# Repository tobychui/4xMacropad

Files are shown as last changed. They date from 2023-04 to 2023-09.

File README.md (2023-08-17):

## CH552G DIY Mechanical Keyboard Archives
This archive stores all the required design files for DIY macropads / keyboard of all sizes and layouts. If you are not experience enough to build one or you just want to get a sample before making a few for yourself, you can also find pre-assembled samples on my [Tindie Store](https://www.tindie.com/stores/tobychui/). 

Gerber files of PCB files will be released with each of the new layout release without the schematics. The schematics will be released following the next layout / design to make sure I got enough funding to iterate more layout and open source them for free. Thank you for your understanding!

## 4xMacropad

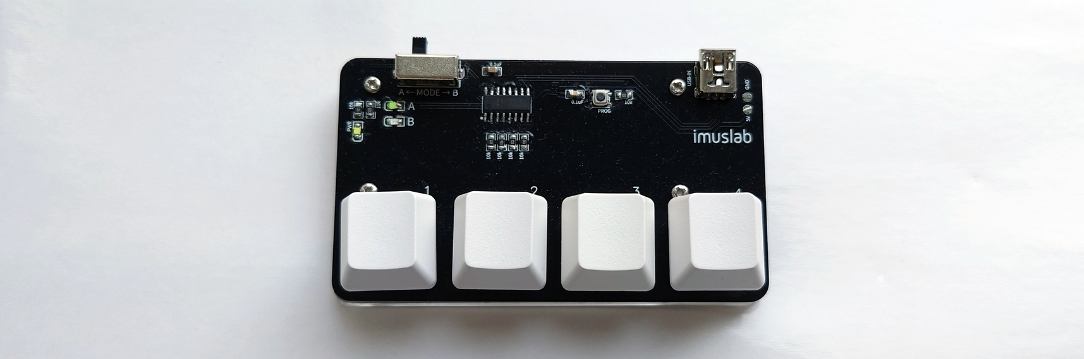
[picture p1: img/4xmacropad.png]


An ultra low cost, 4 keys mechanical macropad using CH552G. See the ```/4xMacropad/ ```folder.

## 4x5 Macro-numpad

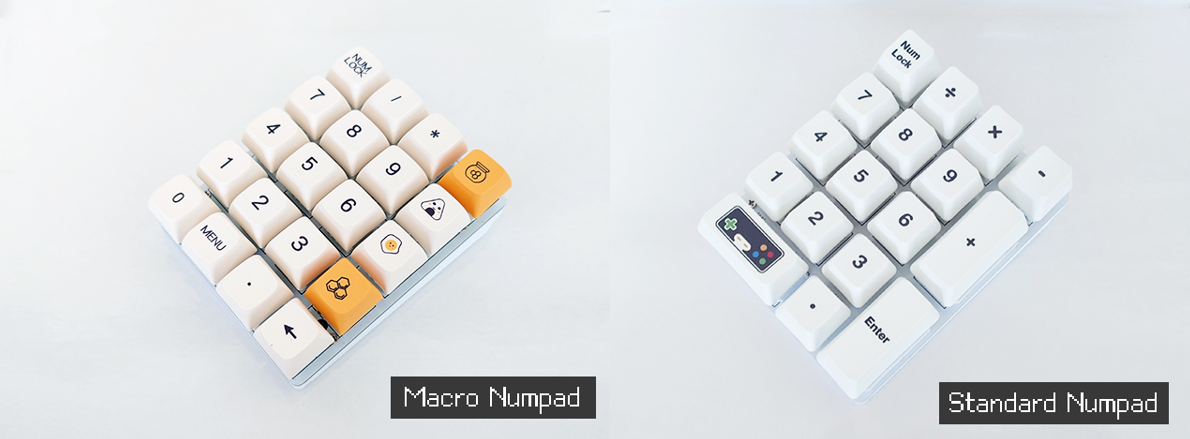
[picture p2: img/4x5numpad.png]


Another ultra low cost macropad + numpad powered by CH552G with two layouts on the same PCB. See the ```/4x5Macro-Numpad/``` folder.

### Build Instruction

1. Send the PCB to print (See /PCB)

2. Purchase all the required materials (See BOM list)

3. 3D print the base plate (See /3D Model)

4. Install the required Arduino library for CH552G and drivers

5. Visit [4-key Macropad | imuslab](https://tobychui.github.io/4xMacropad/) (4xMacropad only) or modify the sketch in /firmware folder

6. Flash the CH552G with the sketch

### Program Flashing Instructions

As all the keyboard designs share the same MCU and programming button design, this instruction should be suitable for all the macropads / numpad in this repo.

1. Hold and press the PROG button on the PCB

2. While the button has been held, insert the USB cable into the mini USB port

3. Release the button when the Arduino code has finished compiling and ready to upload (Timing is important)

4. Wait for the upload to complete

### License

Software: MIT License

Hardware: CC BY-NC-SA

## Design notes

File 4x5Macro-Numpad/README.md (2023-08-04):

# 4x5 Macro-Numpad

In this folder, you will find the design files for the 4x5 macro-numpad. This macro-numpad can be arranged in both standard numpad or macro-numpad arrangement, depending on how your populate the PCB. 

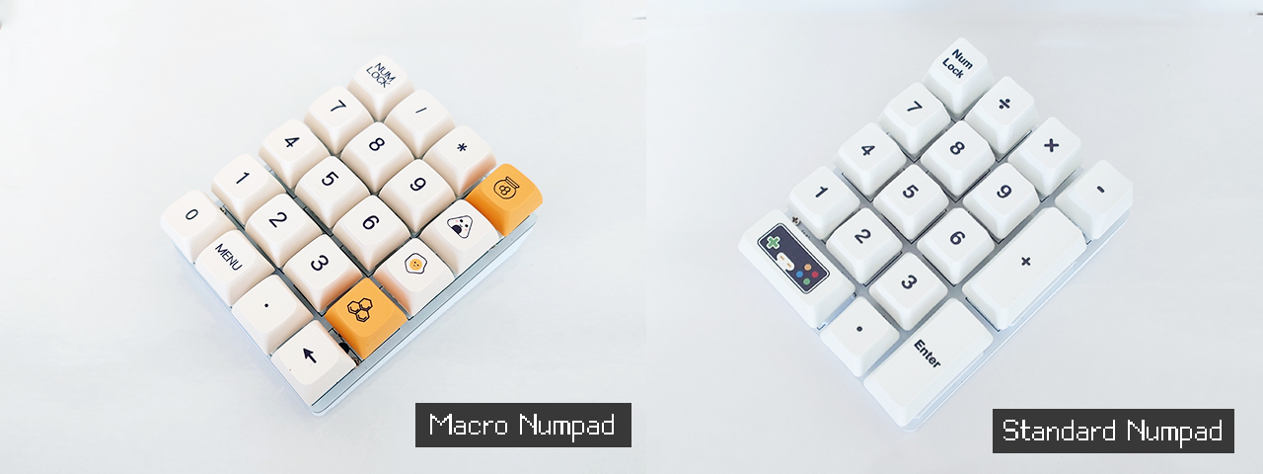
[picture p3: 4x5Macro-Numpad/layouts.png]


The code can be found under the firmware folder. You can edit the code with Arduino IDE.

### Build Instruction

1. Send the PCB to print (See ./pcb)

2. Purchase all the required materials (See BOM list below)

3. 3D print the base plate (See ./models)

4. Install the required Arduino library for CH552G and drivers

5. Modify the sketch in 4x5macro-numpad (for 20 keys layout) or 4x5numpad (for 17 keys layout) 

6. Flash the CH552G with the sketch

#### Programming Tips
In the project folder, you can modify key events by changing the actions.ino file. Each keypress events corrisponding to one key-down and one key-up events. The label of each key-press events have a comment that matches the silk-screen label on the PCB. You can match them accordingly to know which switch you are modifying.

For example, for the switch case
```
// Case: row 2, col 0
```
corrisponding to the ```[2,0]``` switch on the PCB silk screen.

### Program Flashing Instructions

1. Hold and press the PROG button on the PCB

2. While the button has been held, insert the USB cable into the mini USB port

3. Release the button when the Arduino code has finished compiling and ready to upload (Timing is important)

4. Wait for the upload to complete

### Bill of materials

- 0805 LED x 2 (2 different color of your choice)

- 0805 0.1uF x 2

- 0805 10kΩ x 7

- Micro-USB port x 1

- SOP-16 CH552G x 1

- Cherry MX switches x 17 (or 20 if you are using macro-numpad layout)

See USBHIDMediaKeyboard.h for more details.

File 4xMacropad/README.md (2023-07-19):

# 

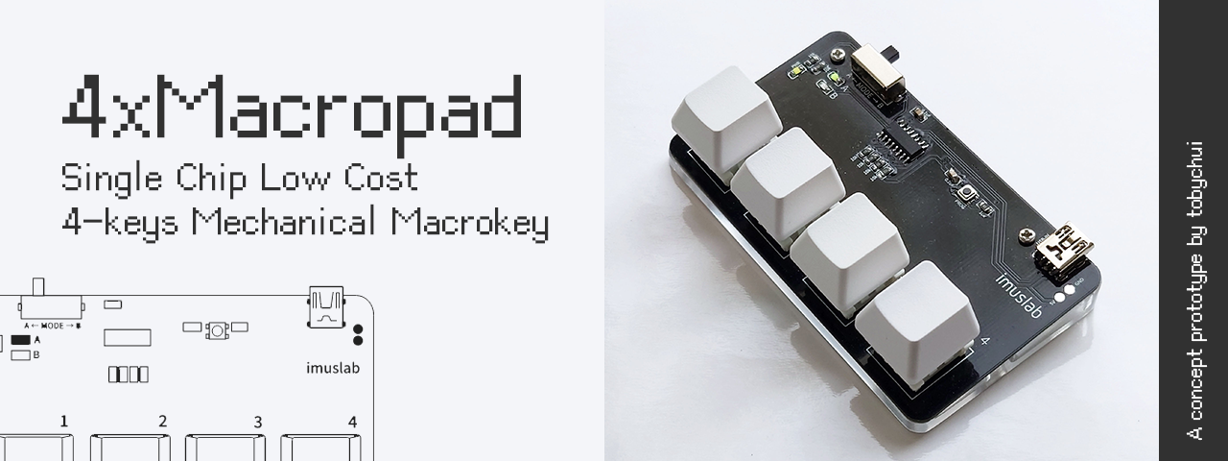
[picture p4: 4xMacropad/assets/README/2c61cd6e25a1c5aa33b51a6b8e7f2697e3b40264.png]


# 4xMacropad

An ultra low cost, 4 keys mechanical macropad using CH552G.

### Build Instruction

1. Send the PCB to print (See ./pcb)

2. Purchase all the required materials (See BOM list below)

3. 3D print the base plate (See ./models)

4. Install the required Arduino library for CH552G and drivers

5. Visit [4-key Macropad | imuslab](https://tobychui.github.io/4xMacropad/) or modify the sketch in macrokey_distribute 

6. Flash the CH552G with the sketch

### Program Flashing Instructions

1. Hold and press the PROG button on the PCB

2. While the button has been held, insert the USB cable into the mini USB port

3. Release the button when the Arduino code has finished compiling and ready to upload (Timing is important)

4. Wait for the upload to complete

### Bill of materials

- 0805 LED x 3 (3 different color of your choice)

- 0805 0.1uF x 2

- 0805 10kΩ x 7

- 3 x 3 x 1.5mm micro switch x 1

- 5PF mini USB port  x 1

- SOP-16 CH552G  x 1

- SK12F14 switch x 1

Optional RGB signal lights on the back of the PCB, if you are going with transparent 3D printed case like mine

- 0805 LED x 3

- 0805 10kΩ x 3

### Photos

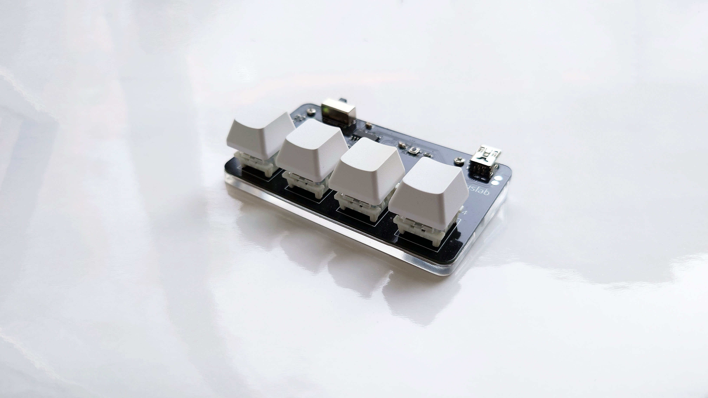
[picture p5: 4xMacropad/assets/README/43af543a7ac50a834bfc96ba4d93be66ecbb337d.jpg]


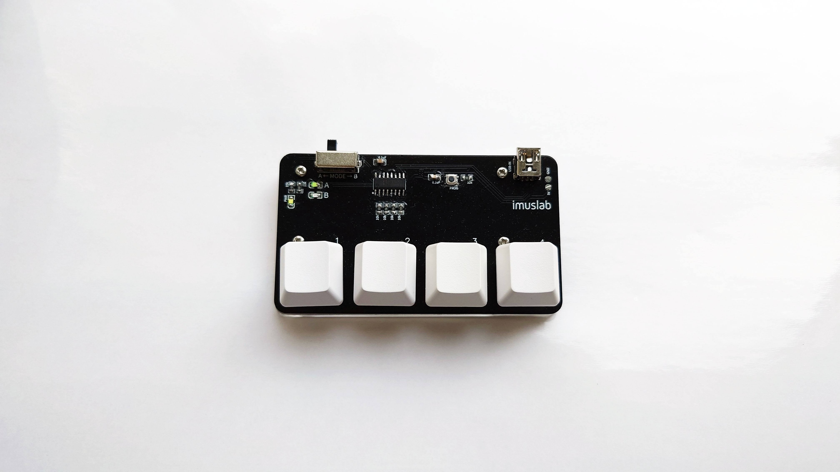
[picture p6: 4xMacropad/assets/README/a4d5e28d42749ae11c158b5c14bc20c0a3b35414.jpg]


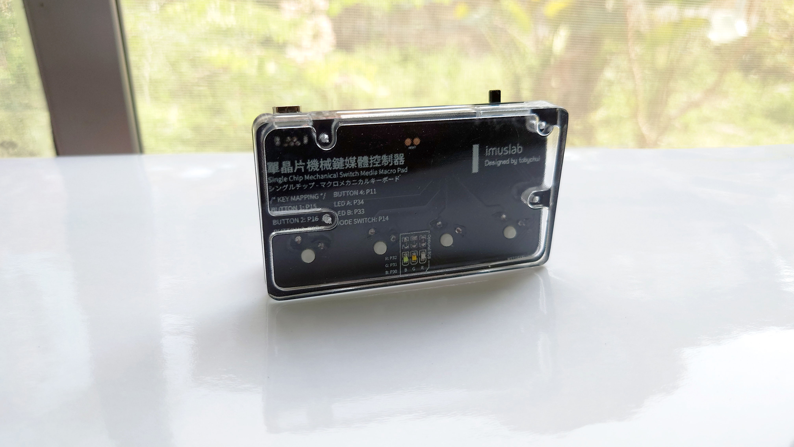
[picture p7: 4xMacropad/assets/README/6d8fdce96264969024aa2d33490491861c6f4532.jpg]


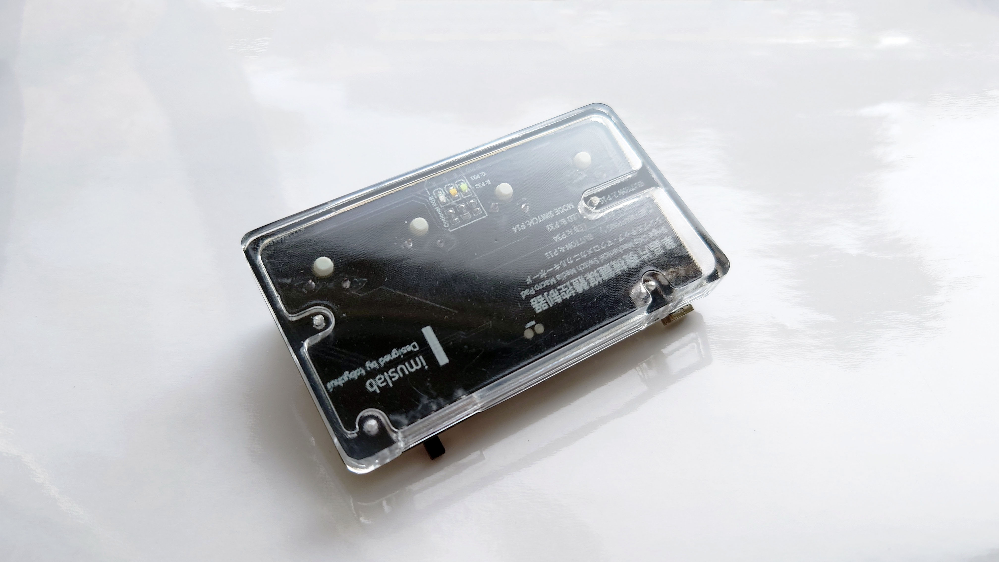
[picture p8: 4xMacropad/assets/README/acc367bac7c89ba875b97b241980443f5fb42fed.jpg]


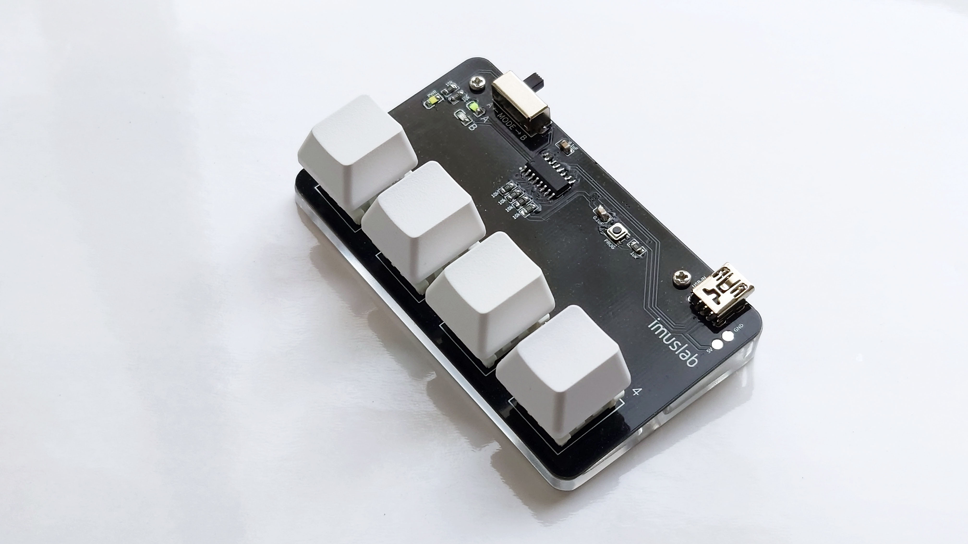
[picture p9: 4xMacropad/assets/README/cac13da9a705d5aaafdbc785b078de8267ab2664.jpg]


# 

See USBHIDMediaKeyboard.h for more details.

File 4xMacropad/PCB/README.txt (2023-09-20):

There are a total of 3 revision of the 4xMacropad. 
The rev 1 is internal testing build in which it screw up so I am not releasing it here.

Rev 2 is the one that you found on hackaday.io and Instructable, also the first few batches
you can get on Tindie.

Rev 3 is an updated version that use micro-USB for input and support 5 pins switches.
If you gonna make one for your self, this is a better options compre to the original v2
which uses the mini-USB port (only if you are good at soldering)

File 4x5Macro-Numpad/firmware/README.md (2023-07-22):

## Firmware Choice Instruction

If you are assembling the PCB with standard numpad layout, use the 4x5numpad firmware

If you are assembling the PCB with macro-numpad layout (aka populate all 20 switches), use the 4x5 macro-numpad layout.

To customize the key presses, see actions.ino. You will need to program the key-down event (i.e. when the key is just pressed) and the key-up event (i.e. when the key is just released) seperately.

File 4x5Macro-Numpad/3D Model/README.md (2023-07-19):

To assemble the case, you will need 4 x M2x5 screws

If you are using the PCB in a standard numpad config, you will also need to print 3 stablizer which can be screw in place to the PCB using a total of 6 M3 x 5 screws.

After the 3D printed base is assembled, you will need another 4 (or 3) M2 x5 screws to fix the PCB onto the base.

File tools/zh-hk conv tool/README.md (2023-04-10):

# Zh-HK Conversion Tool

This tool is designed to work with Python 3 and convert any Traditional Chinese sentence into their corrisponding utf-8 keypress sequence or ALT+DEC CODE for Windows applications.

## Usage

To use this tool, you first need to copy and paste the "win-zh_util.h" file in to the same folder as your arduino .ino file. Next, import the util script into your Arduino code that emulate a USB HID keyboard

```arduino
#include "win-zh_util.h"
```

then you open python IDLE and execute the convert.py file. Follow the on-screen description to enter your setenece and select an encoding method. Here are some example usecase

```
輸入你要轉換的中文句子：這是 big5 的中文輸出
選擇輸出編碼：(utf-8 或 big5)： big5
請把以下輸出複製到 Arduino 的按鍵輸出功能下：

typeChinese("36889"); //這
typeChinese("26159"); //是
Keyboard_write(' ');
Keyboard_write('b');
Keyboard_write('i');
Keyboard_write('g');
Keyboard_write('5');
Keyboard_write(' ');
typeChinese("30340"); //的
typeChinese("20013"); //中
typeChinese("25991"); //文
typeChinese("36664"); //輸
typeChinese("20986"); //出
```

```
輸入你要轉換的中文句子：這是 UTF-8 的中文輸出
選擇輸出編碼：(utf-8 或 big5)： utf-8
請把以下輸出複製到 Arduino 的按鍵輸出功能下：

typeChinese("45935"); //這
typeChinese("44111"); //是
Keyboard_write(' ');
Keyboard_write('U');
Keyboard_write('T');
Keyboard_write('F');
Keyboard_write('-');
Keyboard_write('8');
Keyboard_write(' ');
typeChinese("43706"); //的
typeChinese("42148"); //中
typeChinese("42213"); //文
typeChinese("49129"); //輸
typeChinese("42328"); //出
```

Afterward, copy the code into your Arduino code and modify anything required.

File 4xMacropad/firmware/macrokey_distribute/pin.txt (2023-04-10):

/* KEY MAPPING */
BUTTON 1: P15
BUTTON 2: P16
BUTTON 3: P17
BUTTON 4: P11

LED A: P34
LED B: P33

MODE SWITCH: P14

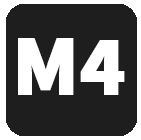
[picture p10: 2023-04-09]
docs/img/pattern.png

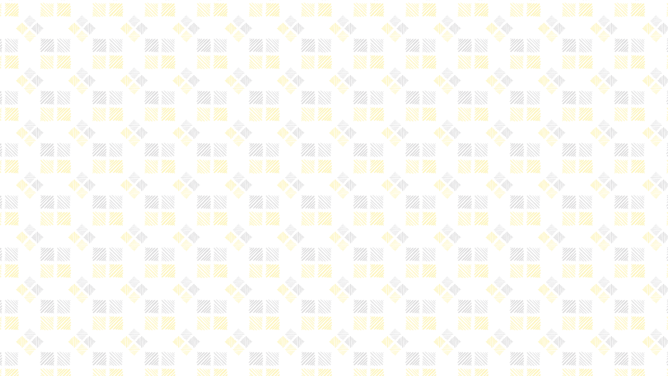
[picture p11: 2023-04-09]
docs/img/tile_background.png

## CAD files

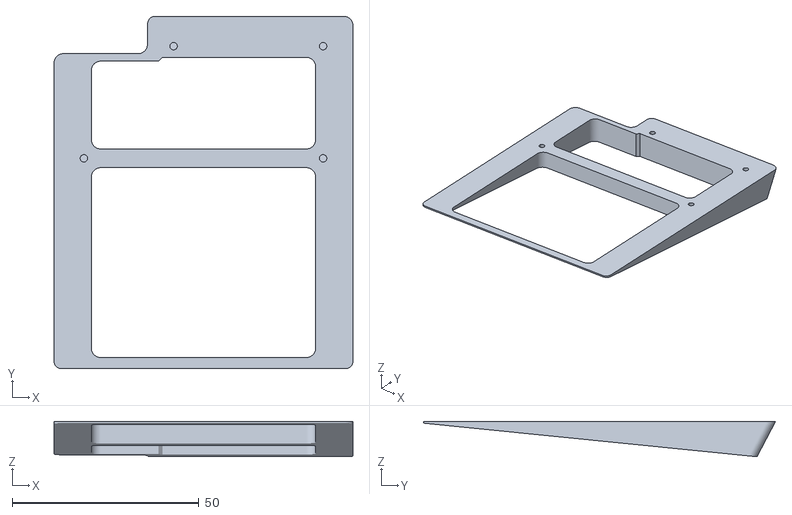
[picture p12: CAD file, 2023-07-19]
4x5Macro-Numpad/3D Model/legs 1 rev2.stl
80.0 x 94.3 x 9.50

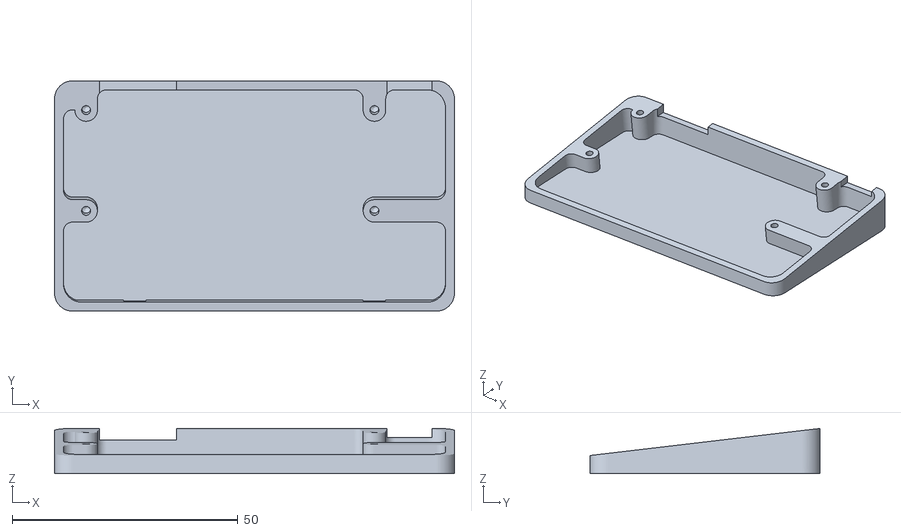
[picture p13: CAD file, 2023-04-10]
4xMacropad/3D Model/base.stl
88.6 x 51.0 x 10.0

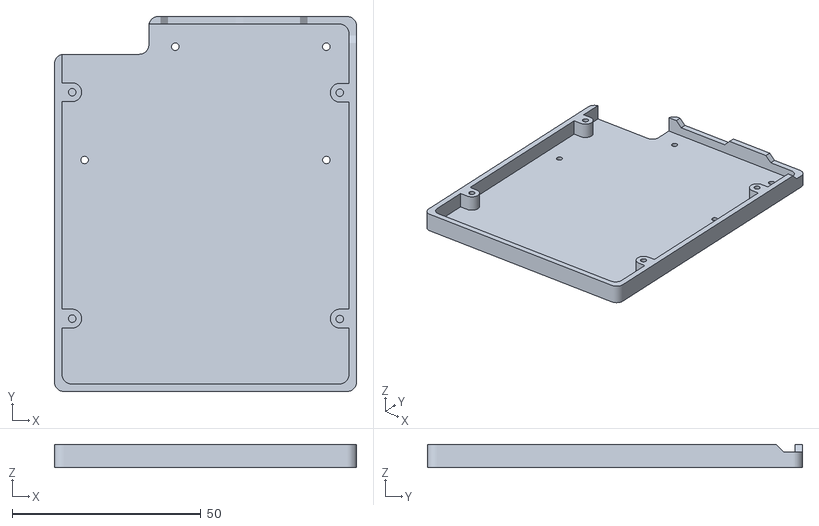
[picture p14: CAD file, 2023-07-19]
4x5Macro-Numpad/3D Model/base.stl
80.0 x 99.3 x 6.20

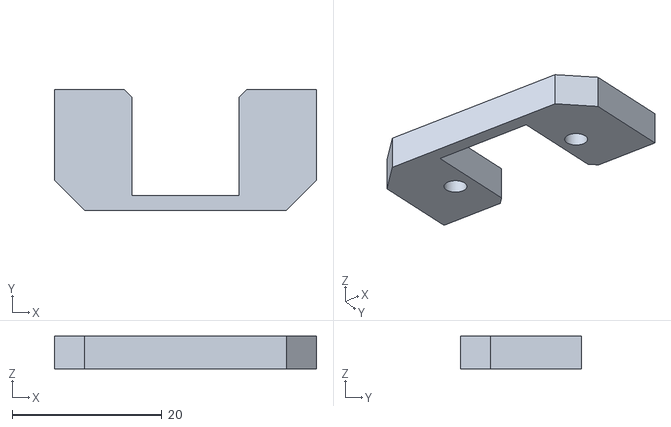
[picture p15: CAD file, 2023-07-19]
4x5Macro-Numpad/3D Model/switch_stabalizer.stl
35.0 x 16.1 x 4.40

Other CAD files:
4x5Macro-Numpad/3D Model/base.ipt
4x5Macro-Numpad/3D Model/legs v1 rev2.ipt
4x5Macro-Numpad/3D Model/switch_stabalizer.ipt
4xMacropad/3D Model/base.ipt

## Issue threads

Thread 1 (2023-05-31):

Would you consider releasing the PCB Project files?

WNiels, 2023-05-31:
Love your design and would like to fiddle around with it! Could you therefore release the project files for the PCB?

tobychui, 2023-07-19:
Oh sorry @WNiels  I missed this issue. I have added it to the PCB folder (See the json file under 4xmacropad/pcb, you shd be able to import it to EasyEDA and export to other formats if needed) , happy making!

Closed 2023-07-19.

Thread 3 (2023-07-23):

4x5MacroPad PCB Project files

KonniLol, 2023-07-23:
Really like your design but I'd like change a few things. I've seen that you have added the json for the 4Key Pad and was wondering if you could also add the project files for the 4x5 Pad.

tobychui, 2023-07-23:
Yes, I will open source it later after I have sell enough of them (est. around 10 - 15 units, or 4 - 5 if I mark up the price a bit higher) on Tindie to make up for the development cost of this project (and if possible, fund part of my next keyboard R&D which is a 34-key split layout keyboard).

Delaying the release of the schematics can prevent / delay clones that manufacture them for sale before I can break-even the cost of developing new design and publishing them for free online.  As you might have notice, my goal is to try to make mechanical keyboards much more easy to make and affordable for everyone.

Sorry that I need to keep you waiting on this. If you like, you can click the "Watch" button on the top right of the repo so when I upload the json file, you can have it asap :)

Thank you for the understanding!

KonniLol, 2023-07-23:
No problem, I totally understand.

tobychui, 2023-10-22:
Closing this issue as PCB file already released

Closed 2023-10-22.

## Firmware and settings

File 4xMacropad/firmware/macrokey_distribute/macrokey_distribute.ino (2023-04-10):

/*
    Toby's Low Cost Macro Keyboard
*/

#ifndef USER_USB_RAM
#error "Require USB RAM. Go Tools > USB Setting and pick the 2nd option in the dropdown list"
#endif

#include "src/userUsbHidMediaKeyboard/USBHIDMediaKeyboard.h"
#include "win-zh_util.h"

////////////// HARDWARE CONFIG //////////
//Mode LED
#define LED_A 34
#define LED_B 33

//RGB LED
#define LED_Red 32
#define LED_Green 31
#define LED_Blue 30

//Mode switch
#define SWITCH 14

//Button (Mechnical, left to right)
#define BTN_1 15
#define BTN_2 16
#define BTN_3 17
#define BTN_4 11

///////////////// RUNTIME ///////////////
//Current Mode
bool modeA = true;

//Previous button states
bool bt1ActiveState = false;
bool bt2ActiveState = false;
bool bt3ActiveState = false;
bool bt4ActiveState = false;

//Current button states
bool bt1Active = false;
bool bt2Active = false;
bool bt3Active = false;
bool bt4Active = false;

////////////// Special Hotkeys //////////////////
//When Button 2 is hold in mode A, activate volume Mode to 
//allow button 3 and 4 to change volume instead of prev / next song
bool volMode = false;

void setup() {
  USBInit();
  pinMode(SWITCH, INPUT);
  
  //Modes LED
  pinMode(LED_A, OUTPUT);
  pinMode(LED_B, OUTPUT);

  //Bottom RGB LEDs
  //by defaults it follows the LED A or B
  pinMode(LED_Red, OUTPUT);
  pinMode(LED_Green, OUTPUT);
  pinMode(LED_Blue, OUTPUT);
  
  if (!digitalRead(SWITCH)){
    digitalWrite(LED_A, HIGH);
    digitalWrite(LED_B, LOW);

    digitalWrite(LED_Blue, HIGH);
    digitalWrite(LED_Red, LOW);
  }else{
    digitalWrite(LED_A, LOW);
    digitalWrite(LED_B, HIGH);

    digitalWrite(LED_Blue, LOW);
    digitalWrite(LED_Red, HIGH);
  }

  
  //LED G reserve for media controller Button 2 long press
  digitalWrite(LED_Green, LOW);
}

void loop() {
  //Read the mode of the keyboard
  modeA = !digitalRead(SWITCH);

  //Read the button states, default PULL HIGH (aka LOW Activate)
  bt1Active = !digitalRead(BTN_1);
  bt2Active = !digitalRead(BTN_2);
  bt3Active = !digitalRead(BTN_3);
  bt4Active = !digitalRead(BTN_4);

  if (modeA == HIGH){
    //Mode A
    //Media Controller

    //Button 1: Play / Pause
    if (bt1ActiveState != bt1Active){
      bt1ActiveState = bt1Active;
      if (bt1Active){
        Consumer_press(MEDIA_PLAY_PAUSE);
      }else{
        Consumer_release(MEDIA_PLAY_PAUSE);
      }
    }

    //Button 2: Toggle Playlist / Volumn Control Mode
    if (bt2ActiveState != bt2Active){
      bt2ActiveState = bt2Active;
      if (bt2Active){
        volMode = true;
        digitalWrite(LED_Green, HIGH);
      }else{
        volMode = false;
        digitalWrite(LED_Green, LOW);
      }
    }

    //Previous Song / Vol Down
    if (bt3ActiveState != bt3Active){
      bt3ActiveState = bt3Active;
      if (volMode){
         //Button 2 is held
        if (bt3Active){
          Consumer_press(MEDIA_VOLUME_DOWN);
        }else{
          Consumer_release(MEDIA_VOLUME_DOWN);
        }
      }else{
         //Default mode
        if (bt3Active){
          Consumer_press(MEDIA_PREV);
        }else{
          Consumer_release(MEDIA_PREV);
        }
      }
      
    }

    //Button 4: Next Song / Vol Up
    if (bt4ActiveState != bt4Active){
      bt4ActiveState = bt4Active;
       if (volMode){
          //Button 2 is held
          if (bt4Active){
            Consumer_press(MEDIA_VOLUME_UP);
          }else{
            Consumer_release(MEDIA_VOLUME_UP);
          }
       }else{
          //Default mode
          if (bt4Active){
            Consumer_press(MEDIA_NEXT);
          }else{
             Consumer_release(MEDIA_NEXT);
          }
       }
    }

    //Set the status LED
    digitalWrite(LED_A, HIGH);
    digitalWrite(LED_B, LOW);
    digitalWrite(LED_Blue, HIGH);
    digitalWrite(LED_Red, LOW);
  }else{
    //Mode B
    //For printing out information
    
    //Button 1
    if (bt1ActiveState != bt1Active){
      bt1ActiveState = bt1Active;
      if (bt1Active){
        //Open browser
        Consumer_press(CONSUMER_BROWSER_HOME);
        delay(100);
        Consumer_release(CONSUMER_BROWSER_HOME);
        delay(1500);
        //Type website
        Keyboard_write('h');
        delay(30);
        Keyboard_write('t');
        delay(30);
        Keyboard_write('t');
        delay(30);
        Keyboard_write('p');
        delay(30);
        Keyboard_write('s');
        delay(30);
        Keyboard_write(':');
        delay(30);
        Keyboard_write('/');
        delay(30);
        Keyboard_write('/');
        delay(30);
        Keyboard_write('i');
        delay(30);
        Keyboard_write('m');
        delay(30);
        Keyboard_write('u');
        delay(30);
        Keyboard_write('s');
        delay(30);
        Keyboard_write('l');
        delay(30);
        Keyboard_write('a');
        delay(30);
        Keyboard_write('b');
        delay(30);
        Keyboard_write('.');
        delay(30);
        Keyboard_write('c');
        delay(30);
        Keyboard_write('o');
        delay(30);
        Keyboard_write('m');
        delay(30);
        Keyboard_write(KEY_RETURN);
        delay(30);
      }
    }
  
    //Button 2
    if (bt2ActiveState != bt2Active){
      bt2ActiveState = bt2Active;
      if (bt2Active){
        typeChinese("45935"); //這
        typeChinese("44111"); //是
        Keyboard_write(' ');
        Keyboard_write('U');
        Keyboard_write('T');
        Keyboard_write('F');
        Keyboard_write('-');
        Keyboard_write('8');
        Keyboard_write(' ');
        typeChinese("43706"); //的
        typeChinese("42148"); //中
        typeChinese("42213"); //文
        typeChinese("49129"); //輸
        typeChinese("42328"); //出
      }
    }

    //Button 3
    if (bt3ActiveState != bt3Active){
      bt3ActiveState = bt3Active;
      if (bt3Active){
        typeChinese("36889"); //這
        typeChinese("26159"); //是
        Keyboard_write(' ');
        Keyboard_write('b');
        Keyboard_write('i');
        Keyboard_write('g');
        Keyboard_write('5');
        Keyboard_write(' ');
        typeChinese("30340"); //的
        typeChinese("20013"); //中
        typeChinese("25991"); //文
        typeChinese("36664"); //輸
        typeChinese("20986"); //出
      }
    }

    //Button 4
    if (bt4ActiveState != bt4Active){
      bt4ActiveState = bt4Active;
      if (bt4Active){
        Keyboard_write('S');
        Keyboard_write('e');
        Keyboard_write('e');
        Keyboard_write(' ');
        Keyboard_write('m');
        Keyboard_write('o');
        Keyboard_write('r');
        Keyboard_write('e');
        Keyboard_write(' ');
        Keyboard_write('o');
        Keyboard_write('n');
        Keyboard_write(' ');
        Keyboard_write('h');
        Keyboard_write('t');
        Keyboard_write('t');
        Keyboard_write('p');
        Keyboard_write('s');
        Keyboard_write(':');
        Keyboard_write('/');
        Keyboard_write('/');
        Keyboard_write('g');
        Keyboard_write('i');
        Keyboard_write('t');
        Keyboard_write('h');
        Keyboard_write('u');
        Keyboard_write('b');
        Keyboard_write('.');
        Keyboard_write('c');
        Keyboard_write('o');
        Keyboard_write('m');
        Keyboard_write('/');
        Keyboard_write('t');
        Keyboard_write('o');
        Keyboard_write('b');
        Keyboard_write('y');
        Keyboard_write('c');
        Keyboard_write('h');
        Keyboard_write('u');
        Keyboard_write('i');
        Keyboard_write('/');
        Keyboard_write('4');
        Keyboard_write('x');
        Keyboard_write('M');
        Keyboard_write('a');
        Keyboard_write('c');
        Keyboard_write('r');
        Keyboard_write('o');
        Keyboard_write('p');
        Keyboard_write('a');
        Keyboard_write('d');
      }
       
    }
    
    //Set the status LED
    digitalWrite(LED_A, LOW);
    digitalWrite(LED_B, HIGH);
    digitalWrite(LED_Blue, LOW);
    digitalWrite(LED_Red, HIGH);
  }
  
  delay(50);  //naive debouncing
}

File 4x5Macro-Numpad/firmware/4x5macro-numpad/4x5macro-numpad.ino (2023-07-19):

/*
    4x5 Macropad

    if you are using the Numpad arrangement, use the numpad firmware
*/
#ifndef USER_USB_RAM
#error "Require USB RAM. Go Tools > USB Setting and pick the 2nd option in the dropdown list"
#endif

#include "src/userUsbHidMediaKeyboard/USBHIDMediaKeyboard.h"

////////////// HARDWARE CONFIG //////////
//LED OUTPUT
#define LED_OUT 14


//SCAN LINES
//Input Pins. Pull High (When reading is low = pressed)
#define COL_1 15
#define COL_2 16
#define COL_3 17
#define COL_4 11

//Output Pins. Set to low to scan that line
#define ROW_1 32
#define ROW_2 31
#define ROW_3 30
#define ROW_4 34
#define ROW_5 33

///////////////// RUNTIME ///////////////
const int readColSeq[4] = {COL_4, COL_3, COL_2, COL_1};
const int scanRowSeq[5] = {ROW_5, ROW_4, ROW_3, ROW_2, ROW_1};
bool funcMode = false; //If Fn key is hold (Default func key: [0,1]

//The layout is identical to the keypad when view from the front side (i.e. not the MCU side)
int keyPressState[5][4] = {
  {false,false,false,false},
  {false,false,false,false},
  {false,false,false,false},
  {false,false,false,false},
  {false,false,false,false},
};

///////////////// FUNC PROTOTYPES ///////////////
void HandleKeyPressEvents(int row, int col, bool previousState, bool currentState);
void PressNumericAsKeypad(char in);
void UpdateLEDState();


void setup() {
  delay(300);
  USBInit();
  //LED
  pinMode(LED_OUT, OUTPUT);

  //Sensing lines
  pinMode(COL_1, INPUT);
  pinMode(COL_2, INPUT);
  pinMode(COL_3, INPUT);
  pinMode(COL_4, INPUT);

  //Select lines
  pinMode(ROW_1, OUTPUT);
  pinMode(ROW_2, OUTPUT);
  pinMode(ROW_3, OUTPUT);
  pinMode(ROW_4, OUTPUT);
  pinMode(ROW_5, OUTPUT);

  //Set all lines to high (active low)
  digitalWrite(ROW_1, HIGH);
  digitalWrite(ROW_2, HIGH);
  digitalWrite(ROW_3, HIGH);
  digitalWrite(ROW_4, HIGH);
  digitalWrite(ROW_5, HIGH);
}

//Activate the row to be scanned
void setScanningRow(int rowNumber) {
  //Hardcoding the sequence save some RAM and faster :)
  (rowNumber==0)?digitalWrite(scanRowSeq[0], LOW):digitalWrite(scanRowSeq[0], HIGH);
  (rowNumber==1)?digitalWrite(scanRowSeq[1], LOW):digitalWrite(scanRowSeq[1], HIGH);
  (rowNumber==2)?digitalWrite(scanRowSeq[2], LOW):digitalWrite(scanRowSeq[2], HIGH);
  (rowNumber==3)?digitalWrite(scanRowSeq[3], LOW):digitalWrite(scanRowSeq[3], HIGH);
  (rowNumber==4)?digitalWrite(scanRowSeq[4], LOW):digitalWrite(scanRowSeq[4], HIGH);
  
  //Disable all and enable the target one not sure why it is not working
  
  //Activate the target row
  //int targetRowPin = scanRowSeq[rowNumber];
  //digitalWrite(targetRowPin, LOW);
  //delay(50);  //naive debouncing
}

//Read and return the key press status of a given column
//Notes: keys are low activated. When not press, the keys are pull HIGH
bool readKeyPress(int colNumber){
  int readPin = readColSeq[colNumber];
  return (digitalRead(readPin) == 0);
}


//Read all the switches states and update to the global array
void updateSwitchStatus() {
  for (int i = 0; i < 5; i++) {
    //For each of the row, read each of the col switch
    setScanningRow(i);
    for (int j = 0; j < 4; j++) {
      bool isKeyDown = readKeyPress(j);
      bool prevState = keyPressState[i][j];
      if (isKeyDown != prevState){
        //Trigger on change events
        
        HandleKeyPressEvents(i,j,prevState,isKeyDown);
        delay(10); //resp time
      }
      keyPressState[i][j] = isKeyDown;
    }
  }
}

//Update the LED status
void UpdateLEDState(){
  if (funcMode) {
    digitalWrite(LED_OUT, HIGH);
  } else {
    digitalWrite(LED_OUT, LOW);
  }
}

void loop() {
  //Read the mode of the keyboard
  updateSwitchStatus();
  
  //Update the NumLock LED
  UpdateLEDState();
}

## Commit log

2023-04-09 Fixed download button
2023-04-10 Updated codes and README
    [base.ipt, base.stl]
2023-07-01 Added wip 4x5 numpad variant
    [base.ipt, base.stl]
2023-07-01 Updated to fix implementation on repeat delay
    [4x5numpad.ino, actions.ino]
2023-07-19 Added 4x5 macro-numpad design files
    [base.ipt, base.stl, legs 1 rev2.stl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]
2023-07-19 Added PCB Project file (EasyEDA)
2023-09-20 Added 4xmacropad v3
    + Microusb port added
    + Switch from 3 pin to 5 pin switches
